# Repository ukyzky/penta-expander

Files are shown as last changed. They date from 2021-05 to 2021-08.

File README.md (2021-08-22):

# penta-expander

## ryo penta sequencer expander (eurorack 4HP)

Currently manufacturing no problem. It works fine.

## function

- per step **trigger** output
- per step on/off switch
- summed **trigger** output
- hold on/off switch
- hold input (signal high: hold on)

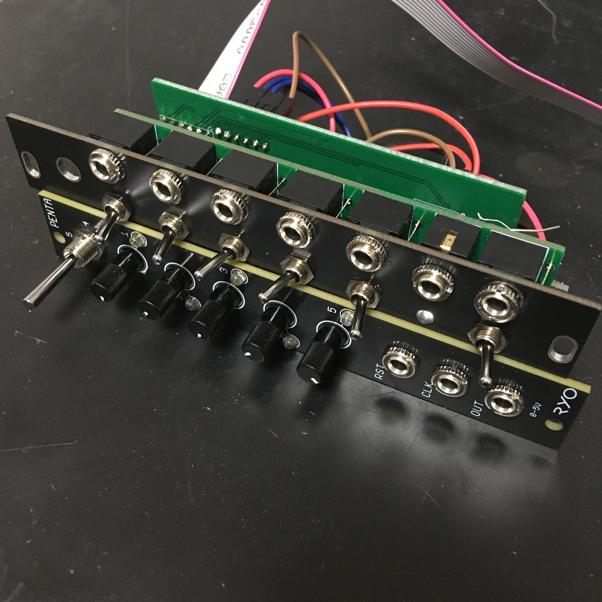
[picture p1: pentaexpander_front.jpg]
Front image


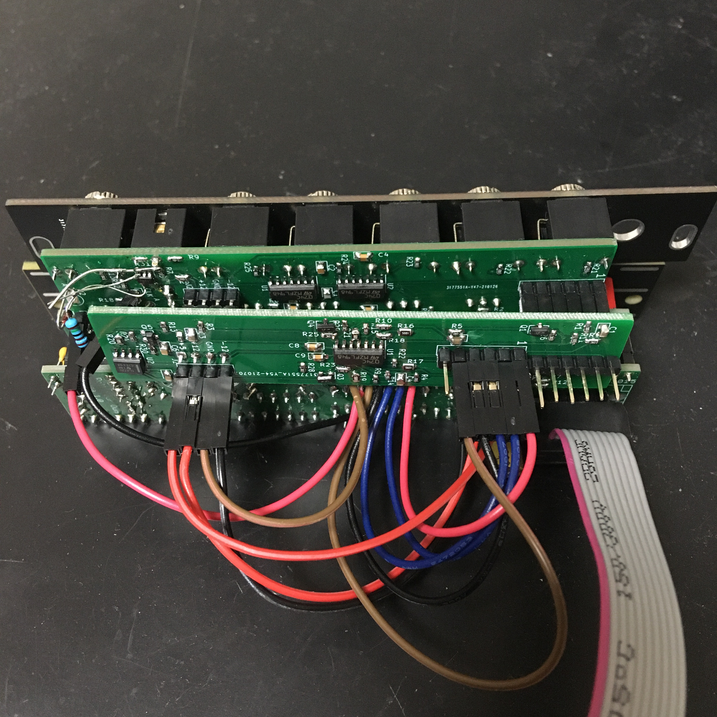
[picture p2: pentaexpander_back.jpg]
Back image


## notes

pcb v1 is main function.

pcb v1plus is sub function of gate to trigger converter x5.

If using pcb v1 only, it becomes per step gate output and summed gate output.
In summed gate output, it has a problem that a step produces 2 triggers because the step fall down signal overwraps the next step's clock.

If using pcb v1 and v1plus, it becomes per step trigger output and summed trigger output.
Above gate problem is resolved.

## bom

refer kicad files.

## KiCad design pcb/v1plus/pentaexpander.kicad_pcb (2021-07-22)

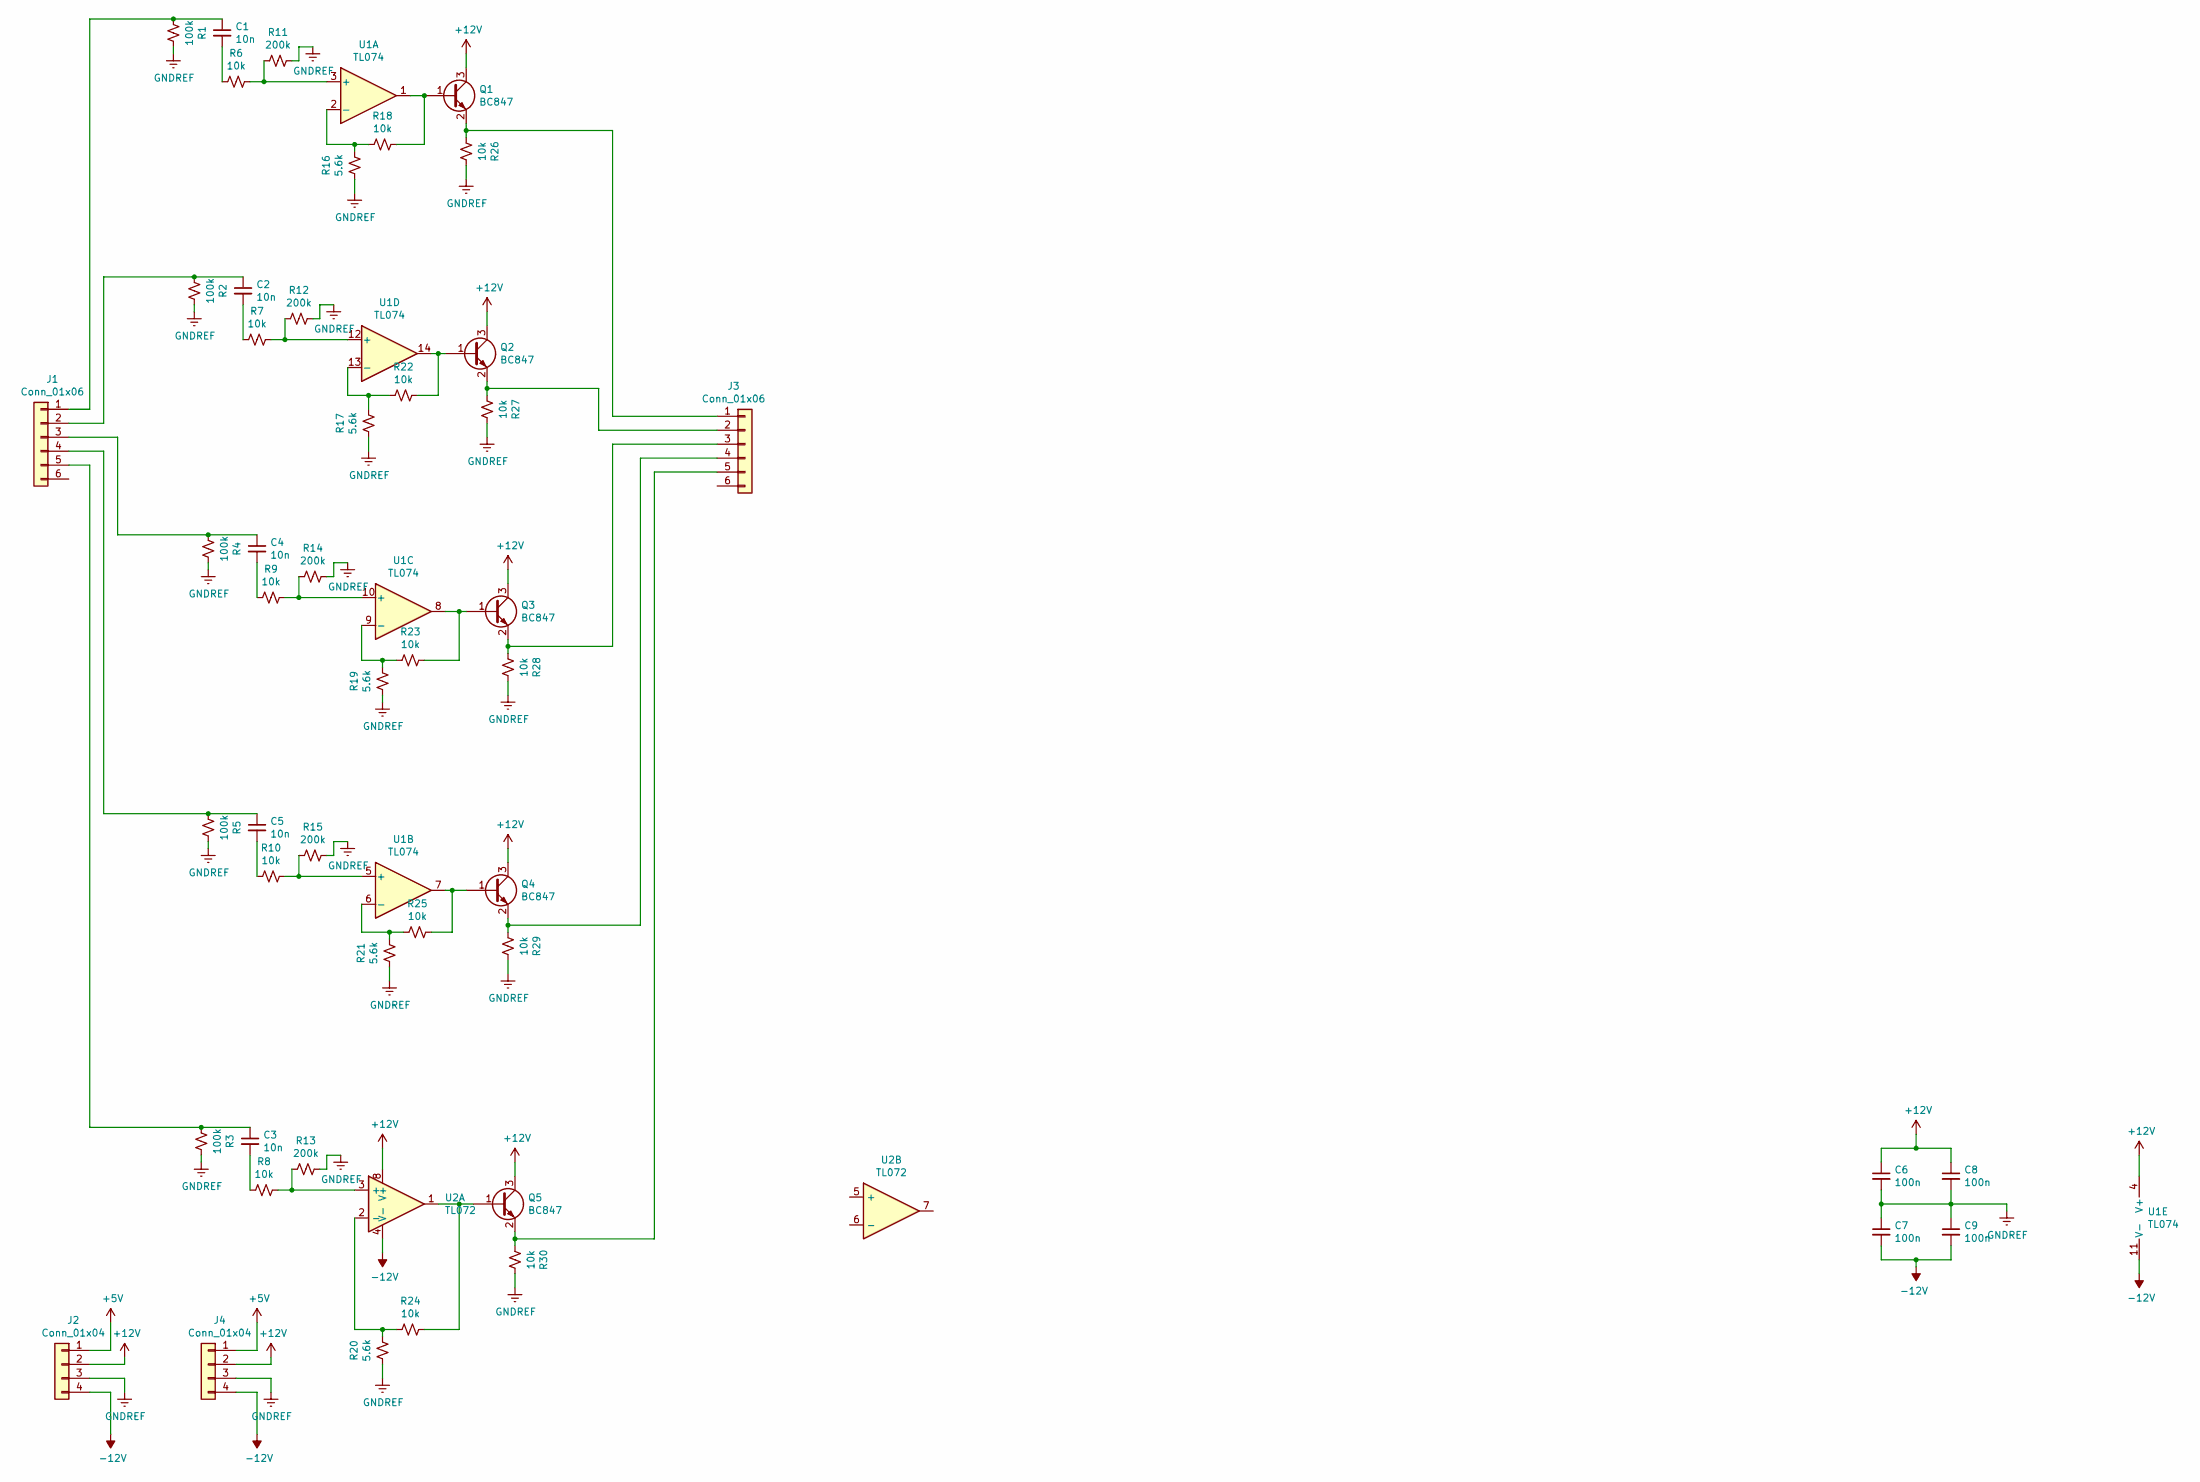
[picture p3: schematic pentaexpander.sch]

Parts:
C1, C2, C3, C4, C5: 10n; D_0805_2012Metric_Pad1.15x1.40mm_HandSolder
C6, C7, C8, C9: 100n; D_0805_2012Metric_Pad1.15x1.40mm_HandSolder
J1, J3: Conn_01x06; Pins_1x06_2.54mm_TH_SWD
J2, J4: Conn_01x04; Pins_1x04_2.54mm_TH
Q1, Q2, Q3, Q4, Q5: BC847; SOT-23
R1, R2, R3, R4, R5: 100k; R_0603_1608Metric_Pad1.05x0.95mm_HandSolder
R6, R7, R8, R9, R10, R18, R22, R23, R24, R25, R26, R27, R28, R29, R30: 10k; R_0603_1608Metric_Pad1.05x0.95mm_HandSolder
R11, R12, R13, R14, R15: 200k; R_0603_1608Metric_Pad1.05x0.95mm_HandSolder
R16, R17, R19, R20, R21: 5.6k; R_0603_1608Metric_Pad1.05x0.95mm_HandSolder
U1: TL074; SOIC-14_3.9x8.7mm_P1.27mm
U2: TL072; SOIC-8_3.9x4.9mm_Pitch1.27mm

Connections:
+5V: J2.1, J4.1
+12V: C6.1, C8.1, J2.2, J4.2, Q1.3 (C), Q2.3 (C), Q3.3 (C), Q4.3 (C), Q5.3 (C), U1.4 (V+), U2.8 (V+)
-12V: C7.2, C9.2, J2.4, J4.4, U1.11 (V-), U2.4 (V-)
GNDREF: C6.2, C7.1, C8.2, C9.1, J2.3, J4.3, R1.1, R2.1, R3.1, R4.1, R5.1, R11.1, R12.1, R13.1, R14.1, R15.1, R16.2, R17.2, R19.2, R20.2, R21.2, R26.1, R27.1, R28.1, R29.1, R30.1
unnamed: C1.1, J1.1, R1.2
unnamed: C1.2, R6.2
unnamed: C2.1, J1.2, R2.2
unnamed: C2.2, R7.2
unnamed: C3.1, J1.5, R3.2
unnamed: C3.2, R8.2
unnamed: C4.1, J1.3, R4.2
unnamed: C4.2, R9.2
unnamed: C5.1, J1.4, R5.2
unnamed: C5.2, R10.2
unnamed: J3.1, Q1.2 (E), R26.2
unnamed: J3.2, Q2.2 (E), R27.2
unnamed: J3.3, Q3.2 (E), R28.2
unnamed: J3.4, Q4.2 (E), R29.2
unnamed: J3.5, Q5.2 (E), R30.2
unnamed: Q1.1 (B), R18.1, U1.1
unnamed: Q2.1 (B), R22.1, U1.14
unnamed: Q3.1 (B), R23.1, U1.8
unnamed: Q4.1 (B), R25.1, U1.7
unnamed: Q5.1 (B), R24.1, U2.1
unnamed: R10.1, R15.2, U1.5 (+)
unnamed: R6.1, R11.2, U1.3 (+)
unnamed: R7.1, R12.2, U1.12 (+)
unnamed: R8.1, R13.2, U2.3 (+)
unnamed: R9.1, R14.2, U1.10 (+)
unnamed: R16.1, R18.2, U1.2 (-)
unnamed: R17.1, R22.2, U1.13 (-)
unnamed: R19.1, R23.2, U1.9 (-)
unnamed: R20.1, R24.2, U2.2 (-)
unnamed: R21.1, R25.2, U1.6 (-)

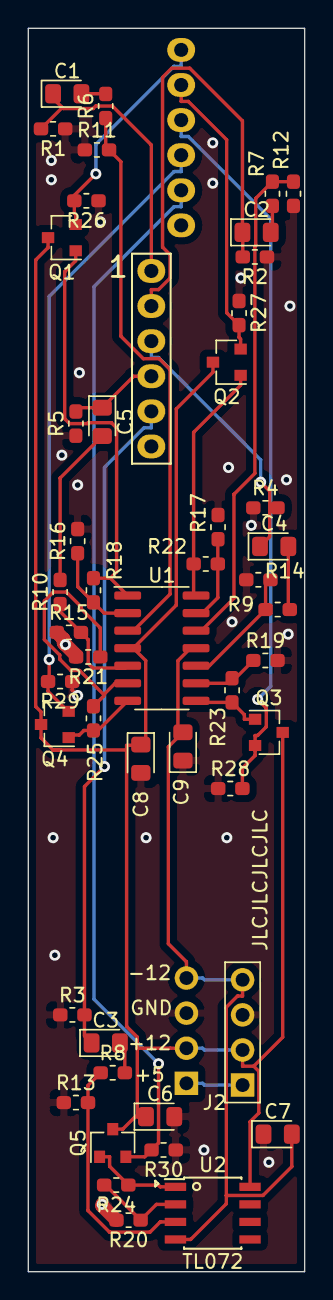
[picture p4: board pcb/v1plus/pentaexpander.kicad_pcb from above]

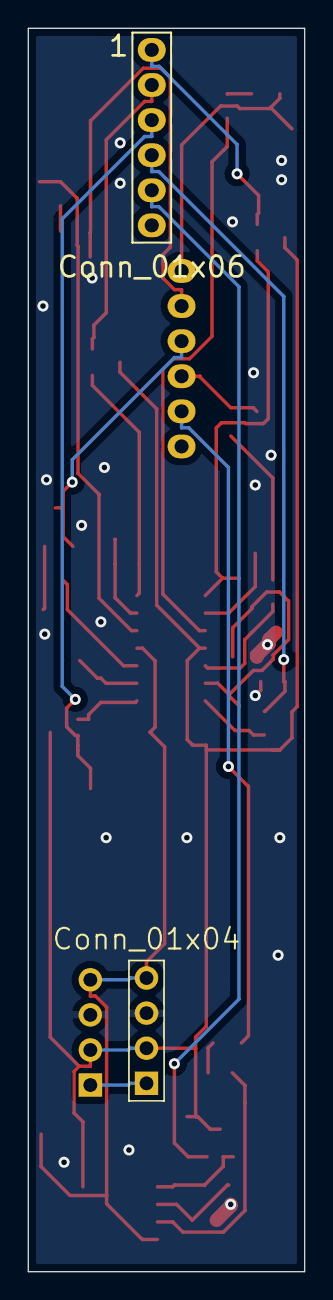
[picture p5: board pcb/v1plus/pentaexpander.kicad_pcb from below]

Board: 2 copper layers, 20.0 x 90.0 mm, 50 parts (2 on the bottom side), 34 nets.

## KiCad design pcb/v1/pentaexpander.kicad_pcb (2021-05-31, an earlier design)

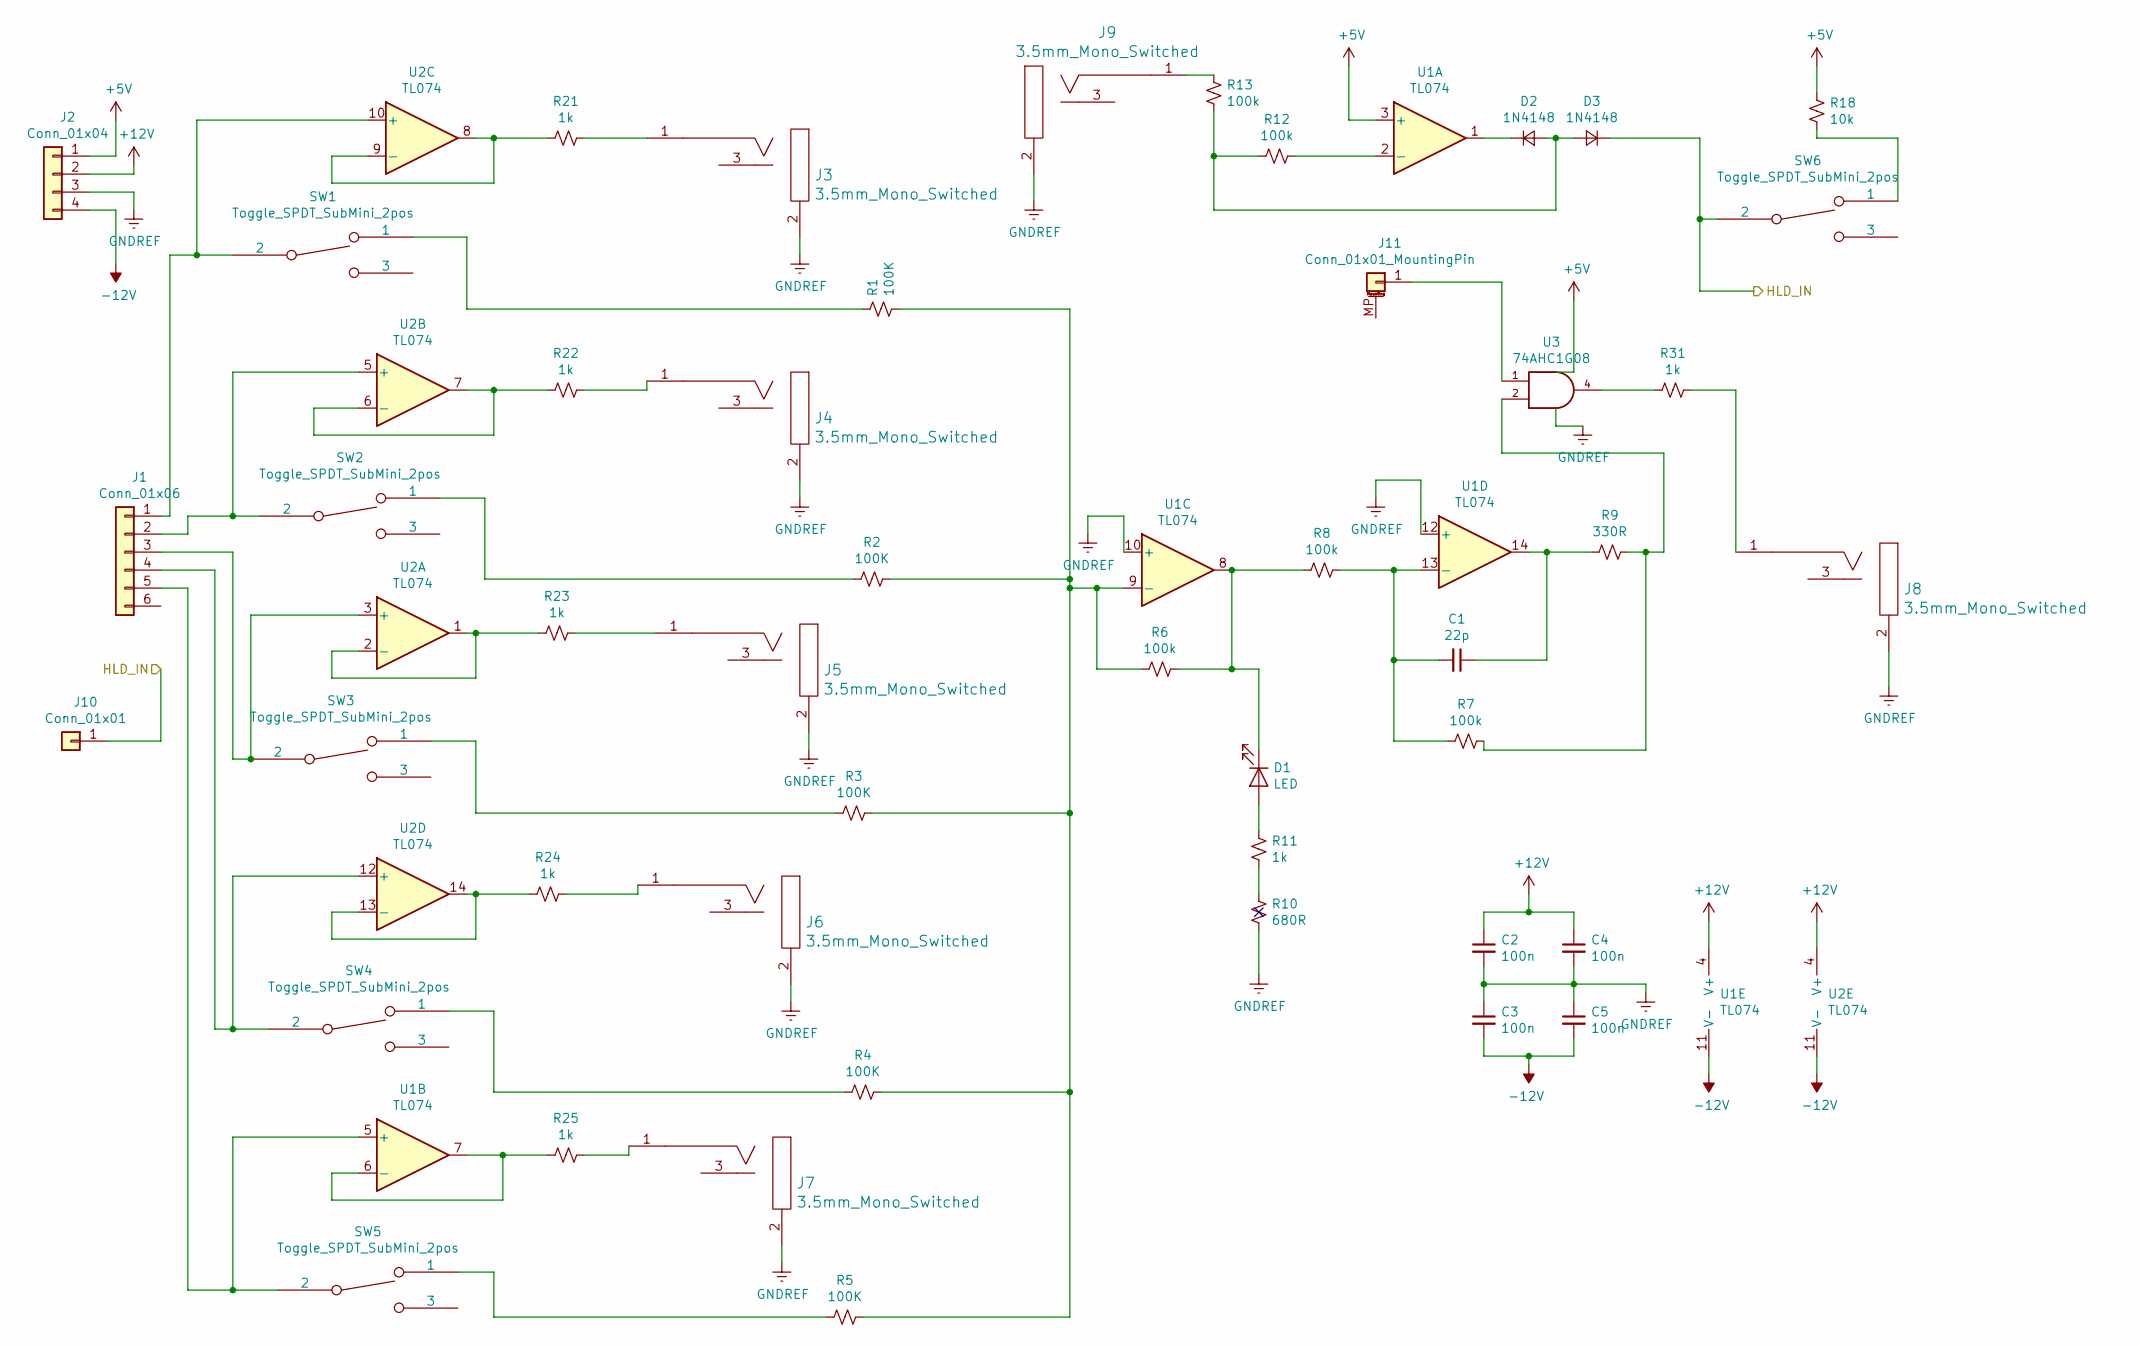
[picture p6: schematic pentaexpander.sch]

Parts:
C1: 22p; D_0805_2012Metric_Pad1.15x1.40mm_HandSolder
C2, C3, C4, C5: 100n; D_0805_2012Metric_Pad1.15x1.40mm_HandSolder
D1: LED; LED_D3.0mm
D2, D3: 1N4148; D_DO-15_P2.54mm_Vertical_AnodeUp
J1: Conn_01x06; Pins_1x06_2.54mm_TH_SWD
J2: Conn_01x04; Pins_1x04_2.54mm_TH
J3, J4, J5, J6, J7, J8, J9: 3.5mm_Mono_Switched; EighthInch_PJ398SM; Part Number WQP-WQP518MA
J10: Conn_01x01; PinHeader_1x01_P2.54mm_Vertical
J11: Conn_01x01_MountingPin; PinHeader_1x01_P2.54mm_Vertical
R1, R2, R3, R4, R5: 100K; R_0603_1608Metric_Pad1.05x0.95mm_HandSolder
R6, R7, R8, R12, R13: 100k; R_0603_1608Metric_Pad1.05x0.95mm_HandSolder
R9: 330R; R_0603_1608Metric_Pad1.05x0.95mm_HandSolder
R10: 680R; R_0603_1608Metric_Pad1.05x0.95mm_HandSolder
R11, R21, R22, R23, R24, R25, R31: 1k; R_0603_1608Metric_Pad1.05x0.95mm_HandSolder
R18: 10k; R_0603_1608Metric_Pad1.05x0.95mm_HandSolder
SW1, SW2, SW3, SW4, SW5, SW6: Toggle_SPDT_SubMini_2pos; Switch_Toggle_SPDT_SubMini; Part Number 200-MSP3-T2B3M2QE
U1, U2: TL074; SOIC-14_3.9x8.7mm_P1.27mm
U3: 74AHC1G08; SOT-23-5_HandSoldering

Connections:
+5V: J2.1, R18.1, U1.3 (+), U3.5 (VCC)
+12V: C2.1, C4.1, J2.2, U1.4 (V+), U2.4 (V+)
-12V: C3.2, C5.2, J2.4, U1.11 (V-), U2.11 (V-)
/HLD_IN: D3.1 (K), J10.1, SW6.2
GND: C2.2, C3.1, C4.2, C5.1, J2.3, J3.2 (SHEILD), J4.2 (SHEILD), J5.2 (SHEILD), J6.2 (SHEILD), J7.2 (SHEILD), J8.2 (SHEILD), J9.2 (SHEILD), R10.2, U1.10 (+), U1.12 (+), U3.3 (GND)
unnamed: C1.1, R9.2, U1.14
unnamed: C1.2, R7.2, R8.1, U1.13 (-)
unnamed: D1.1 (K), R6.1, R8.2, U1.8
unnamed: D1.2 (A), R11.1
unnamed: D2.1 (K), U1.1
unnamed: D2.2 (A), D3.2 (A), R12.2, R13.2
unnamed: J1.1, SW1.2, U2.10 (+)
unnamed: J1.2, SW2.2, U2.5 (+)
unnamed: J1.3, SW3.2, U2.3 (+)
unnamed: J1.4, SW4.2, U2.12 (+)
unnamed: J1.5, SW5.2, U1.5 (+)
unnamed: J3.1 (SIG), R21.1
unnamed: J4.1 (SIG), R22.1
unnamed: J5.1 (SIG), R23.1
unnamed: J6.1 (SIG), R24.1
unnamed: J7.1 (SIG), R25.1
unnamed: J8.1 (SIG), R31.1
unnamed: J9.1 (SIG), R13.1
unnamed 31: J11.1, U3.1; also elsewhere on the board
unnamed: R1.1, SW1.1
unnamed: R1.2, R2.1, R3.1, R4.1, R5.1, R6.2, U1.9 (-)
unnamed: R2.2, SW2.1
unnamed: R3.2, SW3.1
unnamed: R4.2, SW4.1
unnamed: R5.2, SW5.1
unnamed: R7.1, R9.1, U3.2
unnamed: R10.1, R11.2
unnamed: R12.1, U1.2 (-)
unnamed: R18.2, SW6.1
unnamed: R21.2, U2.8, U2.9 (-)
unnamed: R22.2, U2.6 (-), U2.7
unnamed: R23.2, U2.1, U2.2 (-)
unnamed: R24.2, U2.13 (-), U2.14
unnamed: R25.2, U1.6 (-), U1.7
unnamed: R31.2, U3.4

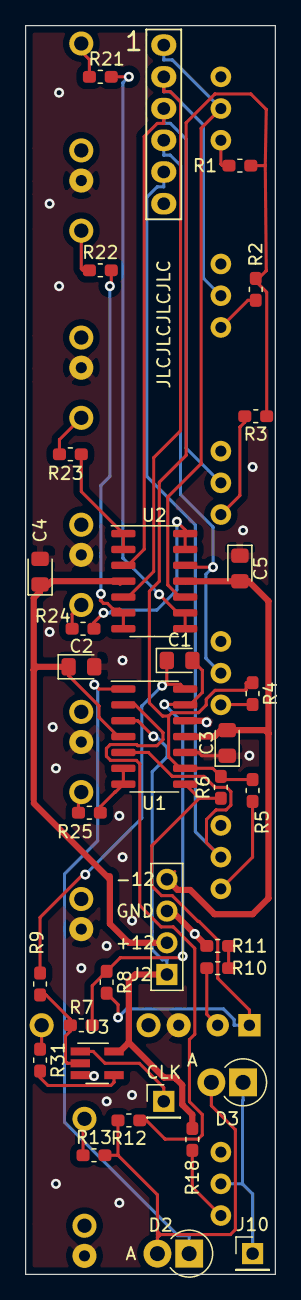
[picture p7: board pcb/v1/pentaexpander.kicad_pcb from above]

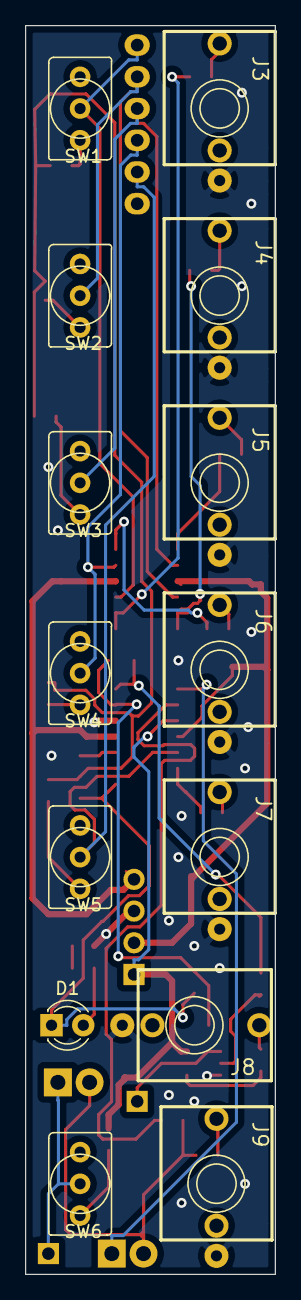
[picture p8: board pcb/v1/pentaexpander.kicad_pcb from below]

Board: 2 copper layers, 20.0 x 100.0 mm, 48 parts (14 on the bottom side), 40 nets.

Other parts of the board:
CLK: Conn_01x01_MountingPin; PinHeader_1x01_P2.54mm_Vertical

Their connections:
unnamed 31: CLK.1; also elsewhere on the board

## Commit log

2021-05-31 Add pcb and panel v1.
    [pentaexpander.kicad_pcb, pentaexpander.sch]
2021-07-22 Add pcb v1plus.
    [pentaexpander.kicad_pcb, pentaexpander.sch]
